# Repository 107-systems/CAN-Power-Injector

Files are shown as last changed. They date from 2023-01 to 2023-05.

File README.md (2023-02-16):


`CAN-Power-Injector`
====================


The purpose of this board is to inject 5V DC power at up to 5A for powering CAN bus devices.

<p align="center">
  
</p>

<p align="center">
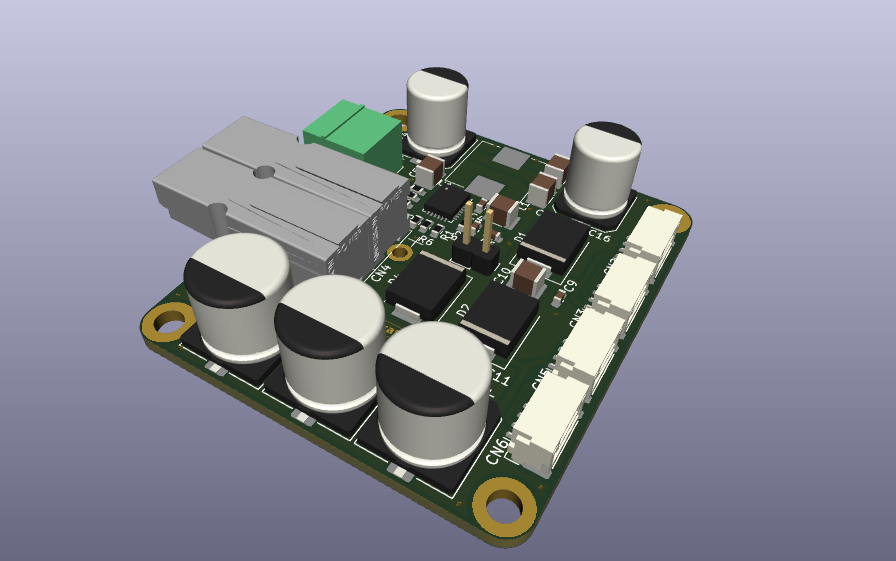
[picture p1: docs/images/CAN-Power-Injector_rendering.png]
  
</p>

#### Blockdiagram
<p align="center">
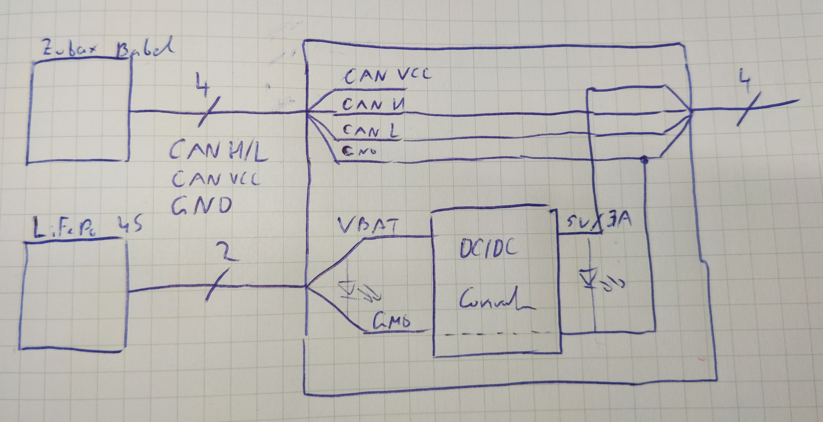
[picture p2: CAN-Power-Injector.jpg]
  
</p>

#### Electrical Parameters
| Name | Value |
|-|-|
| V_IN min | 10.5 V | set by resistor divider(R7/R8) |
| V_IN max | 40.0 V | limited by TVS diode (D4) |
| V_CAN_OUT | 5.0 V to 5.5 V|
| I_CAN_OUT,CONTINUOUS | 5.0 A |

#### Inputs
| Designator | Name | Connector |
|-|-|-|
| CN4 | Battery (4S / 4100 mAh LiFePo) | [Powerpole® PP15 to PP45](https://www.andersonpower.com/content/dam/app/ecommerce/product-pdfs/PP-Pak/ds-pp1545.pdf) |
| CN1 | Battery | 3.5 mm screw terminal (not populated) |

#### Outputs
| Designator | Name | Connector |
|-|-|-|
| CN2 and CN3 | CAN channel 1 | JST GH 1.25mm 4-pin. |
| CN5 and CN6 | CAN channel 2 | JST GH 1.25mm 4-pin. |
| CN7 | 5V | 5V output, internal for testing (not populated) |

## Enclosure

There exists a 3D printable enclosure to encapsulate the PCB.

### Standard
<p align="center">
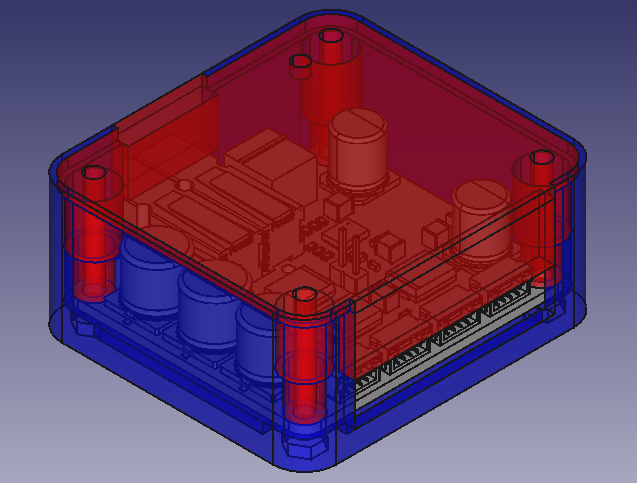
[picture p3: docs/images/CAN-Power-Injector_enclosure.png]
  
</p>

### Low profile
<p align="center">
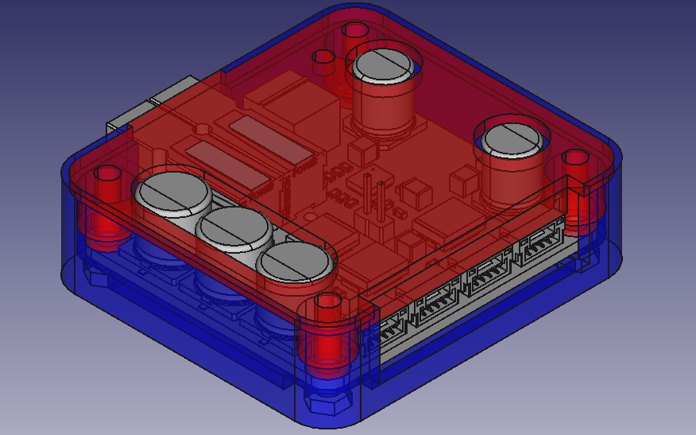
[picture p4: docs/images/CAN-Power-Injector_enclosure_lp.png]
  
</p>

## PCB
### Top
<p align="center">
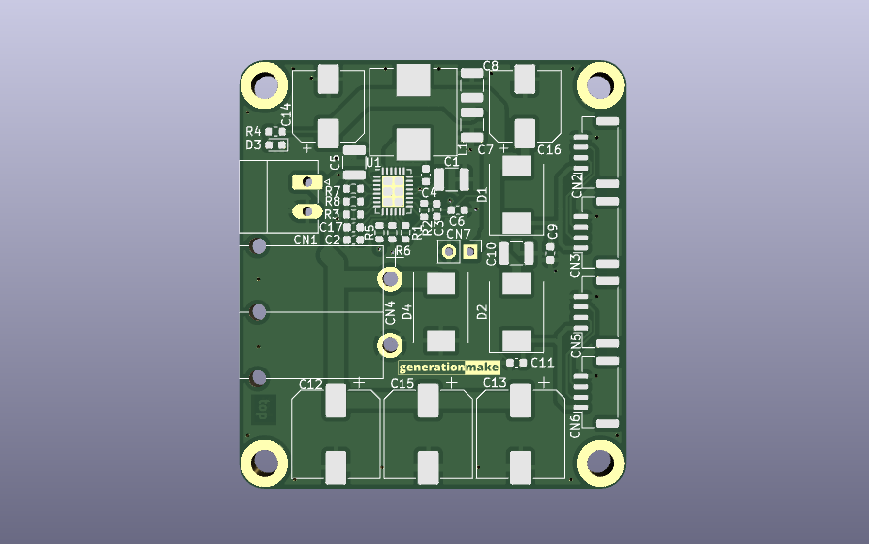
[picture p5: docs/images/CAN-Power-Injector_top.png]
  
</p>

### Bottom
<p align="center">
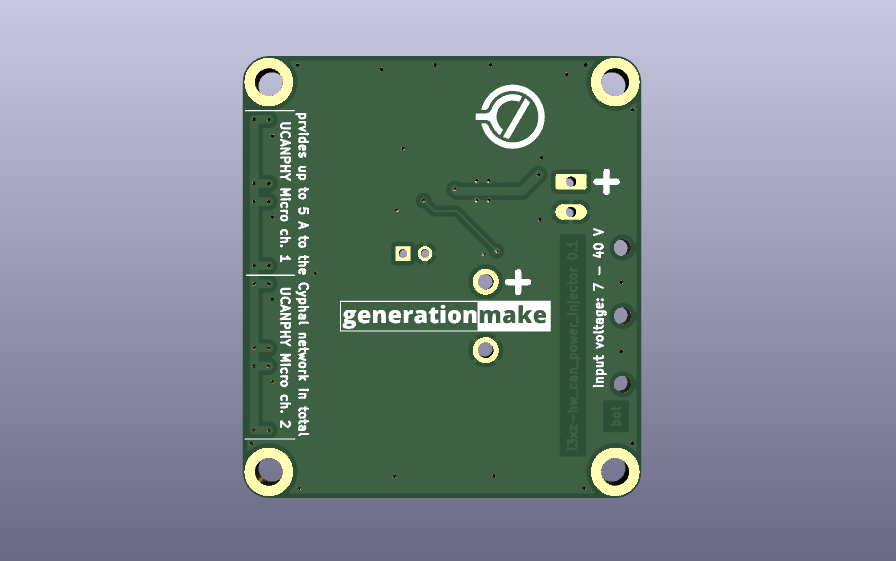
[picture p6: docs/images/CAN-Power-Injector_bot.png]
  
</p>

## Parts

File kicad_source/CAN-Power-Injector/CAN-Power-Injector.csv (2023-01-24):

Source: | /home/bernhard/projects/CAN-Power-Injector/kicad_source/CAN-Power-Injector/CAN-Power-Injector.kicad_sch
Date: | Mi 30 Nov 2022 01:24:45 CET
Tool: | Eeschema 6.0.9-8da3e8f707~116~ubuntu22.04.1
Generator: | /usr/share/kicad/plugins/bom_csv_grouped_by_value.py
Component Count: | 38
Individual Components:
Item | Qty | Reference(s) | Value | LibPart | Footprint | Datasheet
 |  | C1 | 4.7uF 50V | Device:C_Small | Capacitor_SMD:C_1210_3225Metric | ~
 |  | C2 | 1 uF | Device:C_Small | Capacitor_SMD:C_0603_1608Metric | ~
 |  | C3 | 2.2 uF | Device:C_Small | Capacitor_SMD:C_0603_1608Metric | ~
 |  | C4 | 100 nF | Device:C_Small | Capacitor_SMD:C_0603_1608Metric | ~
 |  | C5 | 4.7uF 50V | Device:C_Small | Capacitor_SMD:C_1210_3225Metric | ~
 |  | C6 | 100 nF | Device:C_Small | Capacitor_SMD:C_0603_1608Metric | ~
 |  | C7 | 47uF 10V | Device:C_Small | Capacitor_SMD:C_1210_3225Metric | ~
 |  | C8 | 47uF 10V | Device:C_Small | Capacitor_SMD:C_1210_3225Metric | ~
 |  | C9 | 100 nF | Device:C_Small | Capacitor_SMD:C_0603_1608Metric | ~
 |  | C10 | 47uF 10V | Device:C_Small | Capacitor_SMD:C_1210_3225Metric | ~
 |  | C11 | 100 nF | Device:C_Small | Capacitor_SMD:C_0603_1608Metric | ~
 |  | C12 | 220 uF / 50 V | Device:C_Polarized_Small | Capacitor_SMD:CP_Elec_10x10 | ~
 |  | C13 | 220 uF / 50 V | Device:C_Polarized_Small | Capacitor_SMD:CP_Elec_10x10 | ~
 |  | C14 | 1000 uF / 10 V | Device:C_Polarized_Small | Capacitor_SMD:CP_Elec_8x10 | ~
 |  | C15 | 220 uF / 50 V | Device:C_Polarized_Small | Capacitor_SMD:CP_Elec_10x10 | ~
 |  | C16 | 1000 uF / 10 V | Device:C_Polarized_Small | Capacitor_SMD:CP_Elec_8x10 | ~
 |  | C17 | 10nF | Device:C_Small | Capacitor_SMD:C_0603_1608Metric | ~
 |  | CN1 | DNI | Connector_Generic:Conn_01x02 | Connector_Phoenix_MC:PhoenixContact_MC_1,5_2-G-3.5_1x02_P3.50mm_Horizontal | ~
 |  | CN2 | SM04B-GHS-TB | Connector_Generic_MountingPin:Conn_01x04_MountingPin | Connector_JST:JST_GH_SM04B-GHS-TB_1x04-1MP_P1.25mm_Horizontal | ~
 |  | CN3 | SM04B-GHS-TB | Connector_Generic_MountingPin:Conn_01x04_MountingPin | Connector_JST:JST_GH_SM04B-GHS-TB_1x04-1MP_P1.25mm_Horizontal | ~
 |  | CN4 | Powerpole_2 | Connector_Generic:Conn_01x02 | generationmake:POWERPOLE_hor_2 | ~
 |  | CN5 | SM04B-GHS-TB | Connector_Generic_MountingPin:Conn_01x04_MountingPin | Connector_JST:JST_GH_SM04B-GHS-TB_1x04-1MP_P1.25mm_Horizontal | ~
 |  | CN6 | SM04B-GHS-TB | Connector_Generic_MountingPin:Conn_01x04_MountingPin | Connector_JST:JST_GH_SM04B-GHS-TB_1x04-1MP_P1.25mm_Horizontal | ~
 |  | CN7 | DNI | Connector_Generic:Conn_01x02 | Connector_PinHeader_2.54mm:PinHeader_1x02_P2.54mm_Vertical | ~
 |  | D1 | B520C | Device:D_Schottky_Small | Diode_SMD:D_SMC | ~
 |  | D2 | B520C | Device:D_Schottky_Small | Diode_SMD:D_SMC | ~
 |  | D3 | LED green | Device:LED_Small | LED_SMD:LED_0603_1608Metric | ~
 |  | D4 | SMCJ40A | Device:D_TVS | Diode_SMD:D_SMC | ~
 |  | L1 | 7443251000 (10 uH) | Device:L_Small | Inductor_SMD:L_Wuerth_HCI-1050 | ~
 |  | R1 | 10k | Device:R_Small | Resistor_SMD:R_0603_1608Metric | ~
 |  | R2 | 1R | Device:R_Small | Resistor_SMD:R_0603_1608Metric | ~
 |  | R3 | 30k | Device:R_Small | Resistor_SMD:R_0603_1608Metric | ~
 |  | R4 | 2k2 | Device:R_Small | Resistor_SMD:R_0603_1608Metric | ~
 |  | R5 | 120k | Device:R_Small | Resistor_SMD:R_0603_1608Metric | ~
 |  | R6 | 20k | Device:R_Small | Resistor_SMD:R_0603_1608Metric | ~
 |  | R7 | 120k | Device:R_Small | Resistor_SMD:R_0603_1608Metric | ~
 |  | R8 | 20k | Device:R_Small | Resistor_SMD:R_0603_1608Metric | ~
 |  | U1 | RAA211650 | generationmake:RAA211650 | Package_DFN_QFN:QFN-28-1EP_4x5mm_P0.5mm_EP2.65x3.65mm
Collated Components:
Item | Qty | Reference(s) | Value | LibPart | Footprint | Datasheet
1 | 2 | C1, C5 | 4.7uF 50V | Device:C_Small | Capacitor_SMD:C_1210_3225Metric | ~
2 | 1 | C2 | 1 uF | Device:C_Small | Capacitor_SMD:C_0603_1608Metric | ~
3 | 1 | C3 | 2.2 uF | Device:C_Small | Capacitor_SMD:C_0603_1608Metric | ~
4 | 4 | C4, C6, C9, C11 | 100 nF | Device:C_Small | Capacitor_SMD:C_0603_1608Metric | ~
5 | 3 | C7, C8, C10 | 47uF 10V | Device:C_Small | Capacitor_SMD:C_1210_3225Metric | ~
6 | 3 | C12, C13, C15 | 220 uF / 50 V | Device:C_Polarized_Small | Capacitor_SMD:CP_Elec_10x10 | ~
7 | 2 | C14, C16 | 1000 uF / 10 V | Device:C_Polarized_Small | Capacitor_SMD:CP_Elec_8x10 | ~
8 | 1 | C17 | 10nF | Device:C_Small | Capacitor_SMD:C_0603_1608Metric | ~
9 | 1 | CN1 | DNI | Connector_Generic:Conn_01x02 | Connector_Phoenix_MC:PhoenixContact_MC_1,5_2-G-3.5_1x02_P3.50mm_Horizontal | ~
10 | 4 | CN2, CN3, CN5, CN6 | SM04B-GHS-TB | Connector_Generic_MountingPin:Conn_01x04_MountingPin | Connector_JST:JST_GH_SM04B-GHS-TB_1x04-1MP_P1.25mm_Horizontal | ~
11 | 1 | CN4 | Powerpole_2 | Connector_Generic:Conn_01x02 | generationmake:POWERPOLE_hor_2 | ~
12 | 1 | CN7 | DNI | Connector_Generic:Conn_01x02 | Connector_PinHeader_2.54mm:PinHeader_1x02_P2.54mm_Vertical | ~
13 | 2 | D1, D2 | B520C | Device:D_Schottky_Small | Diode_SMD:D_SMC | ~
14 | 1 | D3 | LED green | Device:LED_Small | LED_SMD:LED_0603_1608Metric | ~
15 | 1 | D4 | SMCJ40A | Device:D_TVS | Diode_SMD:D_SMC | ~
16 | 1 | L1 | 7443251000 (10 uH) | Device:L_Small | Inductor_SMD:L_Wuerth_HCI-1050 | ~
17 | 1 | R1 | 10k | Device:R_Small | Resistor_SMD:R_0603_1608Metric | ~
18 | 1 | R2 | 1R | Device:R_Small | Resistor_SMD:R_0603_1608Metric | ~
19 | 1 | R3 | 30k | Device:R_Small | Resistor_SMD:R_0603_1608Metric | ~
20 | 1 | R4 | 2k2 | Device:R_Small | Resistor_SMD:R_0603_1608Metric | ~
21 | 2 | R5, R7 | 120k | Device:R_Small | Resistor_SMD:R_0603_1608Metric | ~
22 | 2 | R6, R8 | 20k | Device:R_Small | Resistor_SMD:R_0603_1608Metric | ~
23 | 1 | U1 | RAA211650 | generationmake:RAA211650 | Package_DFN_QFN:QFN-28-1EP_4x5mm_P0.5mm_EP2.65x3.65mm

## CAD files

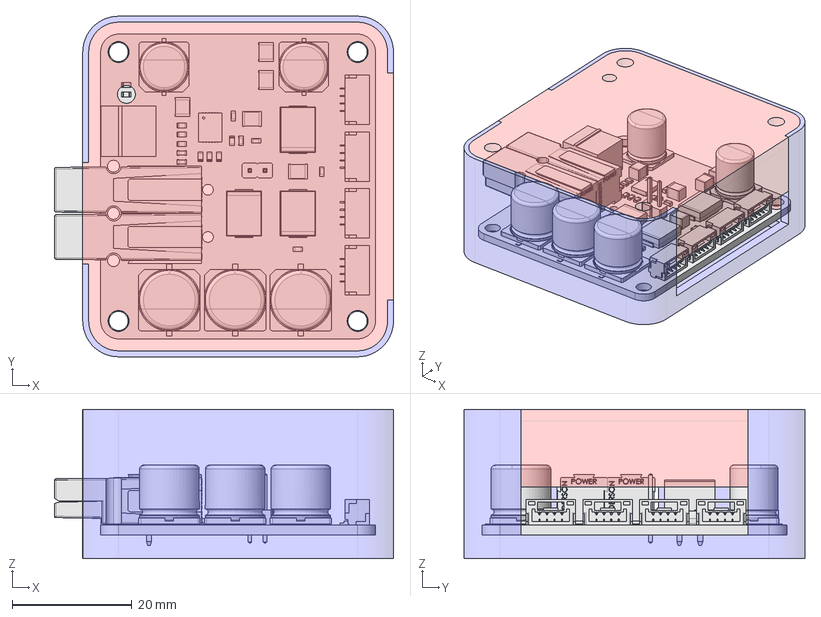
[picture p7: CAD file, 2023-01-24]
freecad_source/enclosure.FCStd
56.7 x 57.0 x 25.0 mm
bottom
l3xz-hw_can_power_injector
top

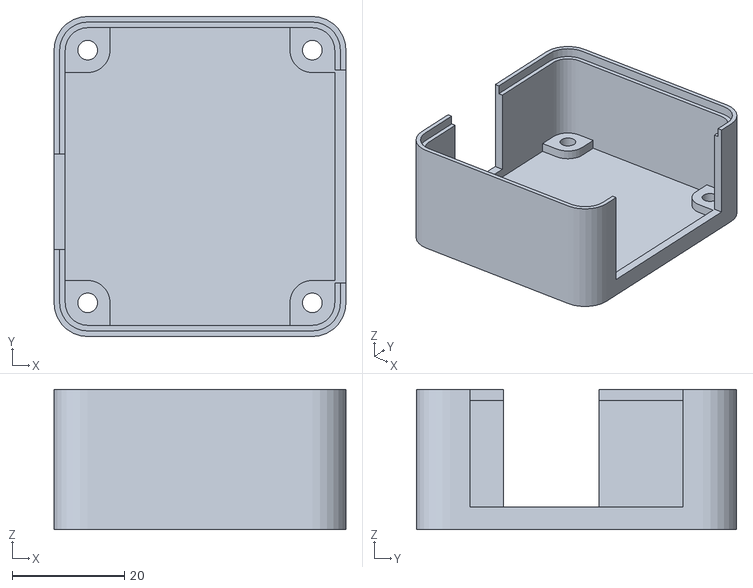
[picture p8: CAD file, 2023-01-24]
production_data/enclosure-bottom.stl
52.0 x 57.0 x 25.0

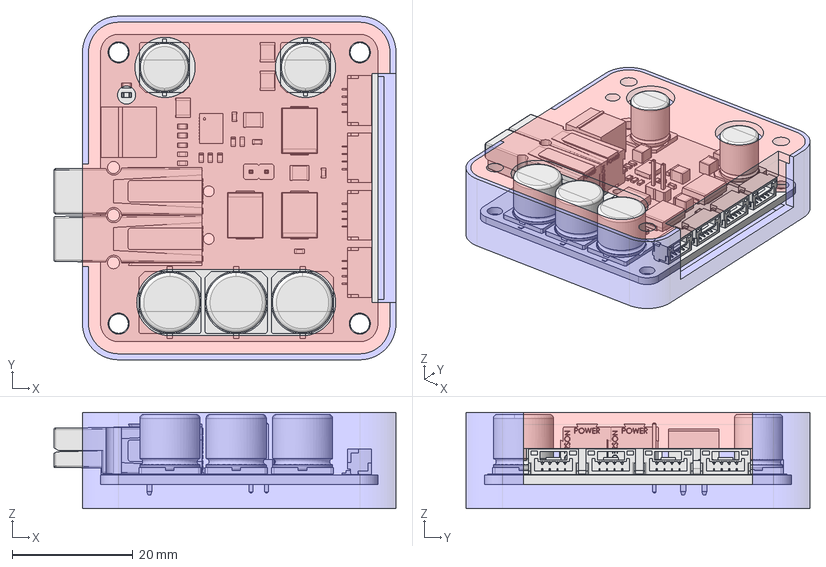
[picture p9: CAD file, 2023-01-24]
freecad_source/enclosure_lp.FCStd
56.7 x 57.0 x 16.0 mm
bottom
l3xz-hw_can_power_injector
top

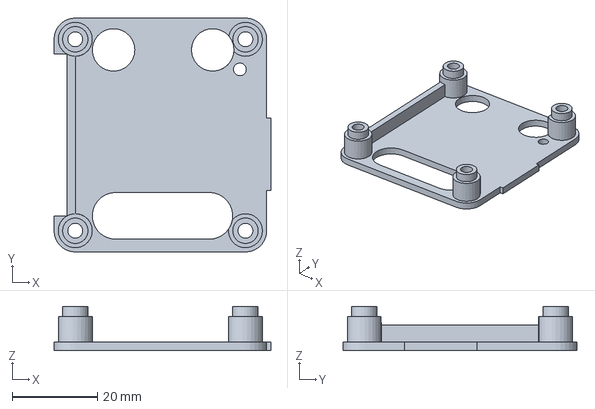
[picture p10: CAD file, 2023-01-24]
production_data/enclosure_lp-top.3mf
51.0 x 55.0 x 10.4 mm

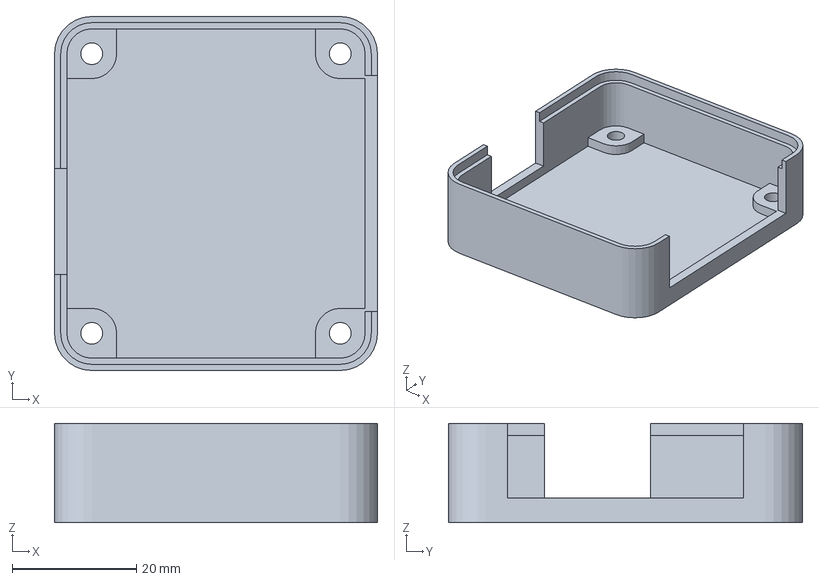
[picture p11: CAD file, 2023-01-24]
production_data/enclosure_lp-bottom.3mf
52.0 x 57.0 x 16.0 mm

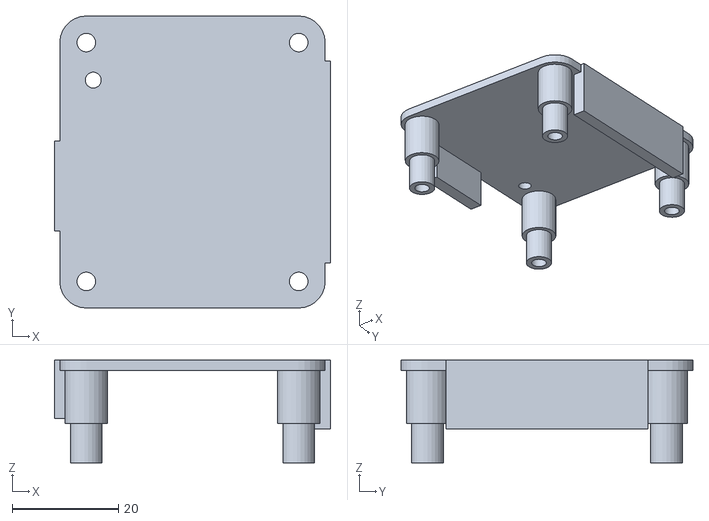
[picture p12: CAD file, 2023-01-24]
production_data/enclosure-top.stl
52.0 x 55.0 x 19.4

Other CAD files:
production_data/enclosure_lp-bottom.stl
production_data/enclosure_lp-top.stl

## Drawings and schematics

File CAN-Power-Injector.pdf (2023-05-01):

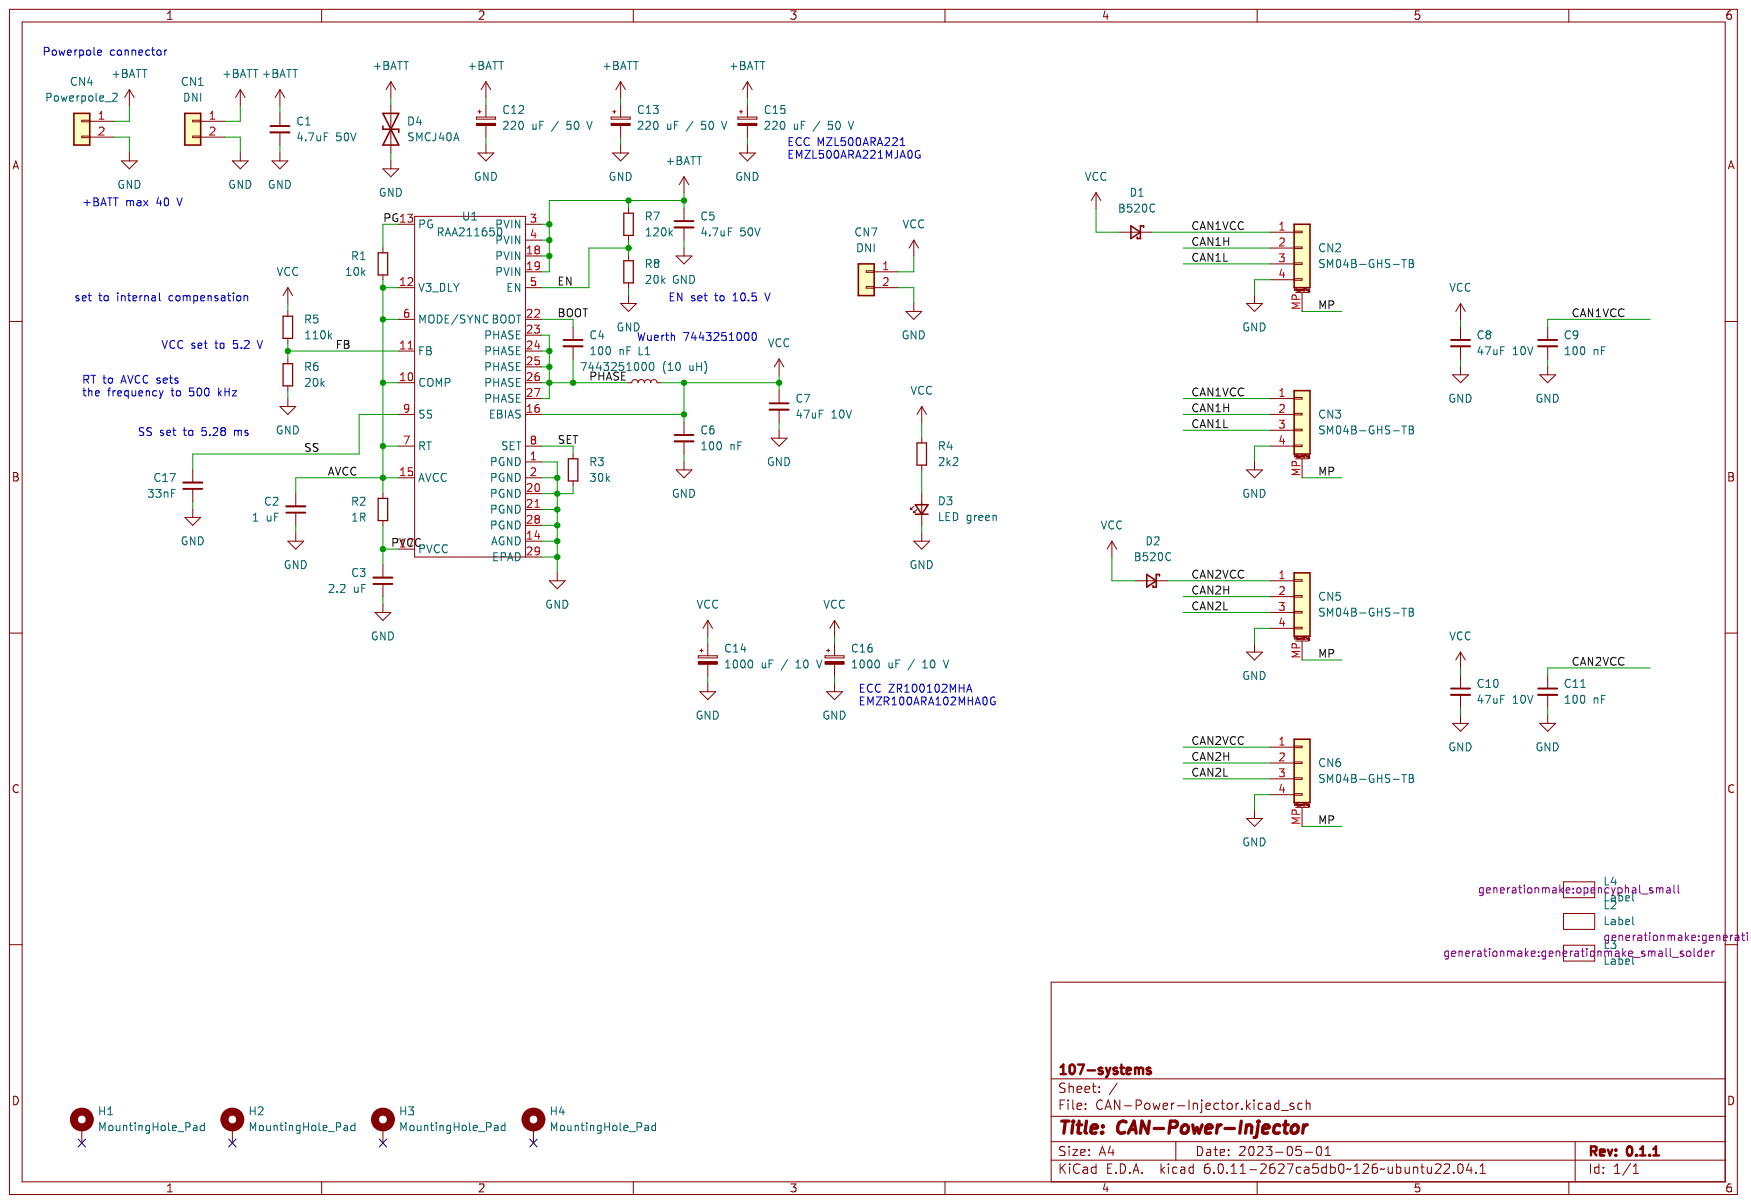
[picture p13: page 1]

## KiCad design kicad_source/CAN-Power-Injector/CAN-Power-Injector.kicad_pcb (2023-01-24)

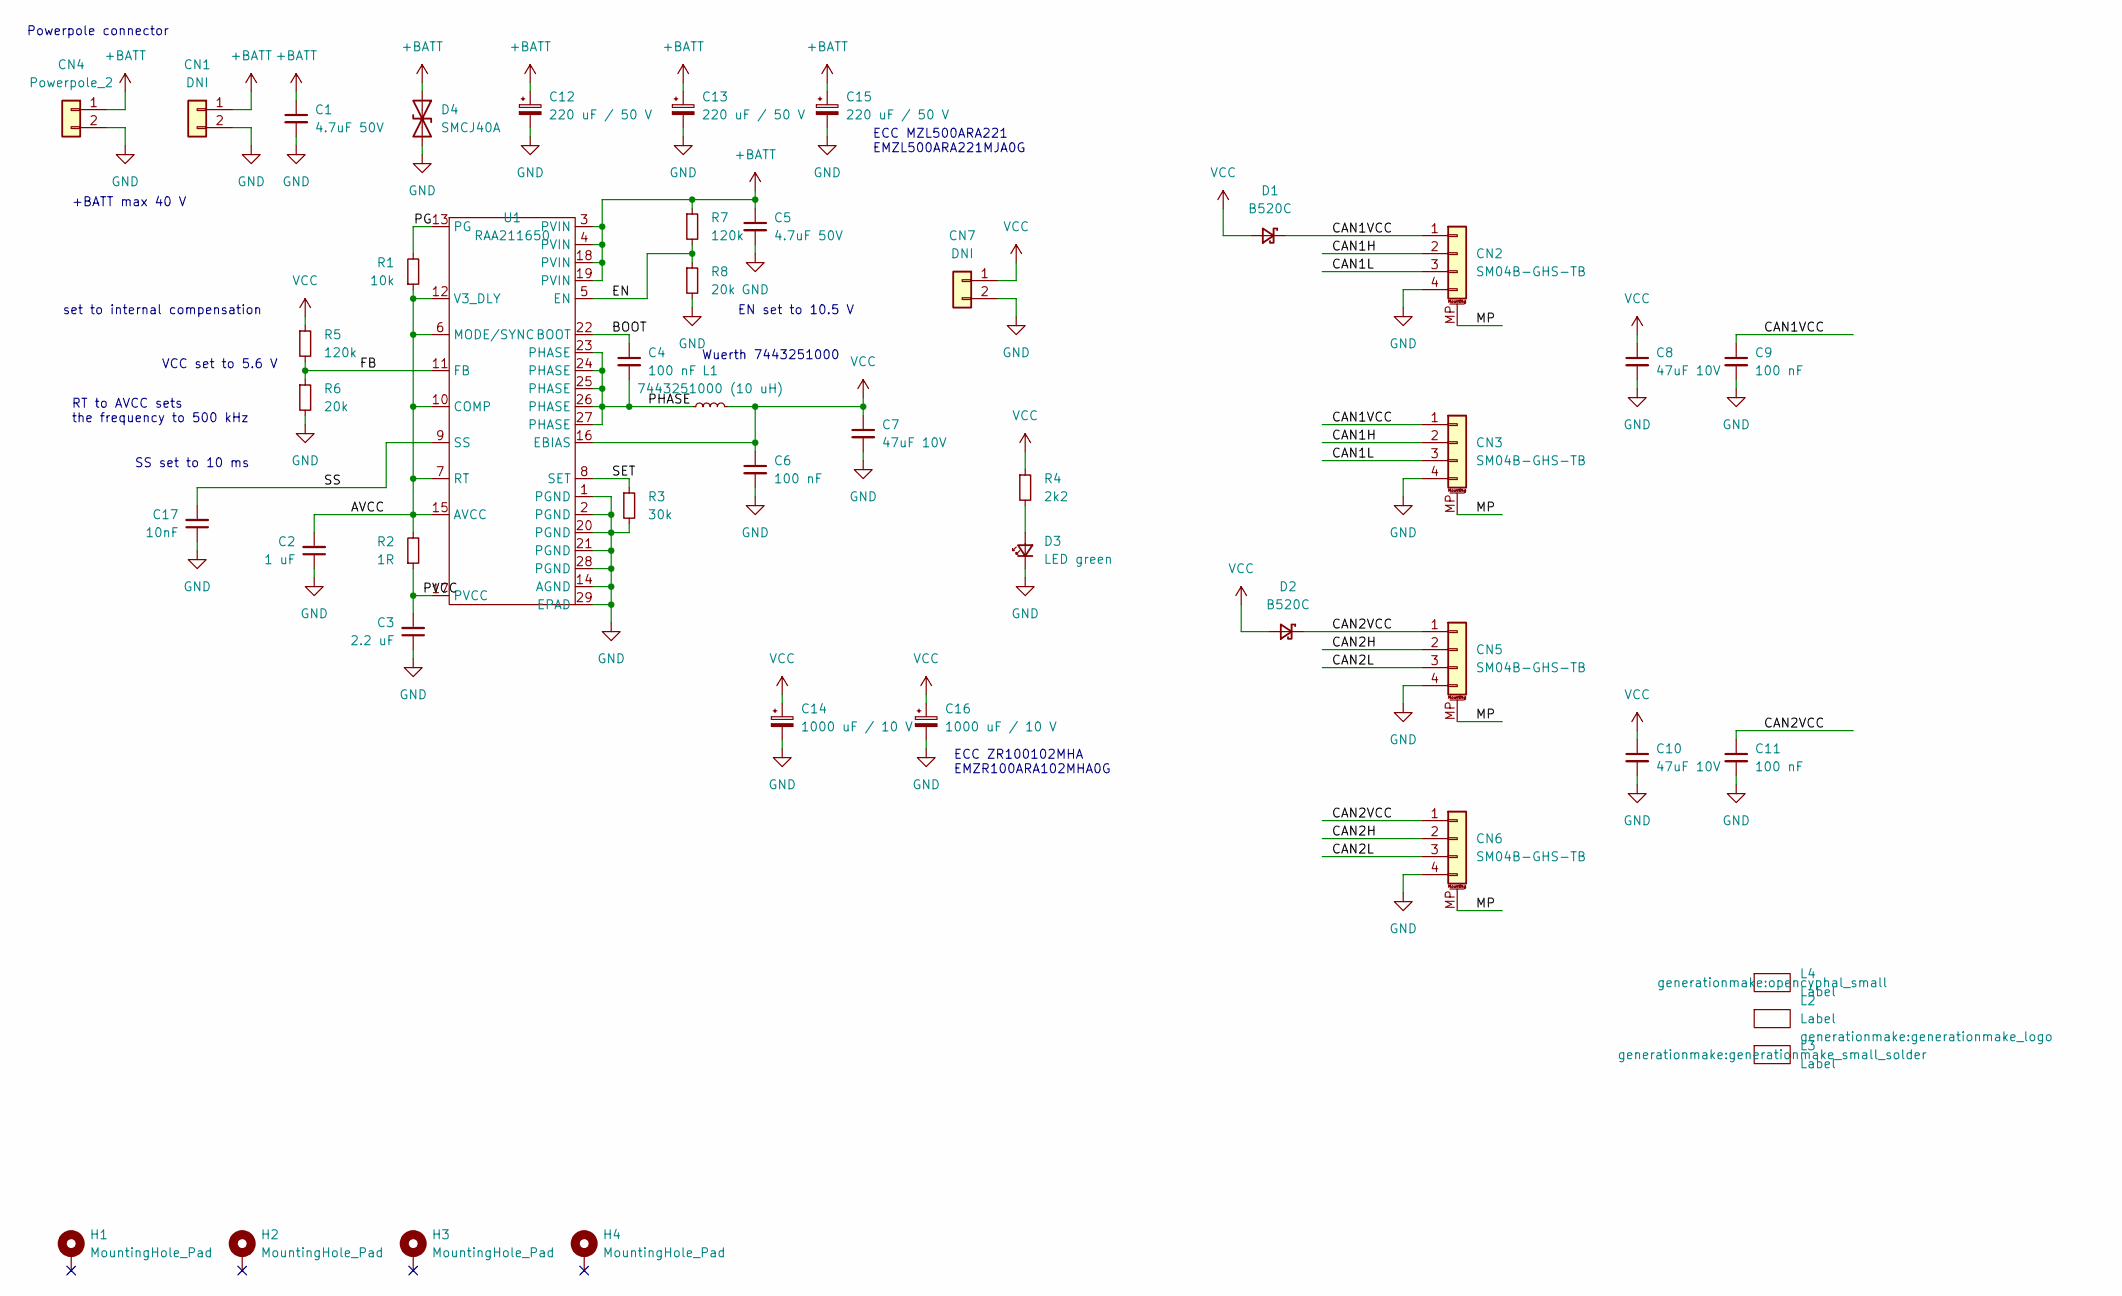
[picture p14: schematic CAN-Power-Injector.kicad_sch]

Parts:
C1, C5: 4.7uF 50V; C_1210_3225Metric
C2: 1 uF; C_0603_1608Metric
C3: 2.2 uF; C_0603_1608Metric
C4, C6, C9, C11: 100 nF; C_0603_1608Metric
C7, C8, C10: 47uF 10V; C_1210_3225Metric
C12, C13, C15: 220 uF / 50 V; CP_Elec_10x10
C14, C16: 1000 uF / 10 V; CP_Elec_8x10
C17: 10nF; C_0603_1608Metric
CN1: DNI; PhoenixContact_MC_1,5_2-G-3.5_1x02_P3.50mm_Horizontal
CN2, CN3, CN5, CN6: SM04B-GHS-TB; JST_GH_SM04B-GHS-TB_1x04-1MP_P1.25mm_Horizontal
CN4: Powerpole_2; POWERPOLE_hor_2
CN7: DNI; PinHeader_1x02_P2.54mm_Vertical
D1, D2: B520C; D_SMC
D3: LED green; LED_0603_1608Metric
D4: SMCJ40A; D_SMC
H1, H2, H3, H4: MountingHole_Pad; MountingHole_3.2mm_M3_DIN965_Pad
L1: 7443251000 (10 uH); L_Wuerth_HCI-1050
L2: Label; generationmake_logo
L3: Label; generationmake_small_solder
L4: Label; opencyphal_small
R1: 10k; R_0603_1608Metric
R2: 1R; R_0603_1608Metric
R3: 30k; R_0603_1608Metric
R4: 2k2; R_0603_1608Metric
R5, R7: 120k; R_0603_1608Metric
R6, R8: 20k; R_0603_1608Metric
U1: RAA211650; QFN-28-1EP_4x5mm_P0.5mm_EP2.65x3.65mm

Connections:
+BATT: C1.1, C5.1, C12.1, C13.1, C15.1, CN1.1, CN4.1, D4.1 (A1), R7.1, U1.3 (PVIN), U1.4 (PVIN), U1.18 (PVIN), U1.19 (PVIN)
/AVCC: C2.2, R1.1, R2.2, U1.6 (MODE/SYNC), U1.7 (RT), U1.10 (COMP), U1.12 (V3_DLY), U1.15 (AVCC)
/BOOT: C4.1, U1.22 (BOOT)
/CAN1H: CN2.2, CN3.2
/CAN1L: CN2.3, CN3.3
/CAN1VCC: C9.1, CN2.1, CN3.1, D1.1 (K)
/CAN2H: CN5.2, CN6.2
/CAN2L: CN5.3, CN6.3
/CAN2VCC: C11.1, CN5.1, CN6.1, D2.1 (K)
/EN: R7.2, R8.1, U1.5 (EN)
/FB: R5.2, R6.1, U1.11 (FB)
/MP: CN2.MP (MountPin), CN3.MP (MountPin), CN5.MP (MountPin), CN6.MP (MountPin)
/PG: R1.2, U1.13 (PG)
/PHASE: C4.2, L1.1, U1.23 (PHASE), U1.24 (PHASE), U1.25 (PHASE), U1.26 (PHASE), U1.27 (PHASE)
/PVCC: C3.2, R2.1, U1.17 (PVCC)
/SET: R3.1, U1.8 (SET)
/SS: C17.2, U1.9 (SS)
GND: C1.2, C2.1, C3.1, C5.2, C6.2, C7.2, C8.2, C9.2, C10.2, C11.2, C12.2, C13.2, C14.2, C15.2, C16.2, C17.1, CN1.2, CN2.4, CN3.4, CN4.2, CN5.4, CN6.4, CN7.2, D3.1 (K), D4.2 (A2), R3.2, R6.2, R8.2, U1.1 (PGND), U1.2 (PGND), U1.14 (AGND), U1.20 (PGND), U1.21 (PGND), U1.28 (PGND), U1.29 (EPAD)
unnamed: D3.2 (A), R4.2
VCC: C6.1, C7.1, C8.1, C10.1, C14.1, C16.1, CN7.1, D1.2 (A), D2.2 (A), L1.2, R4.1, R5.1, U1.16 (EBIAS)

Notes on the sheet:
Wuerth 7443251000
EN set to 10.5 V
+BATT max 40 V
ECC ZR100102MHA EMZR100ARA102MHA0G
set to internal compensation
ECC MZL500ARA221 EMZL500ARA221MJA0G
RT to AVCC sets the frequency to 500 kHz
VCC set to 5.6 V
Powerpole connector
SS set to 10 ms

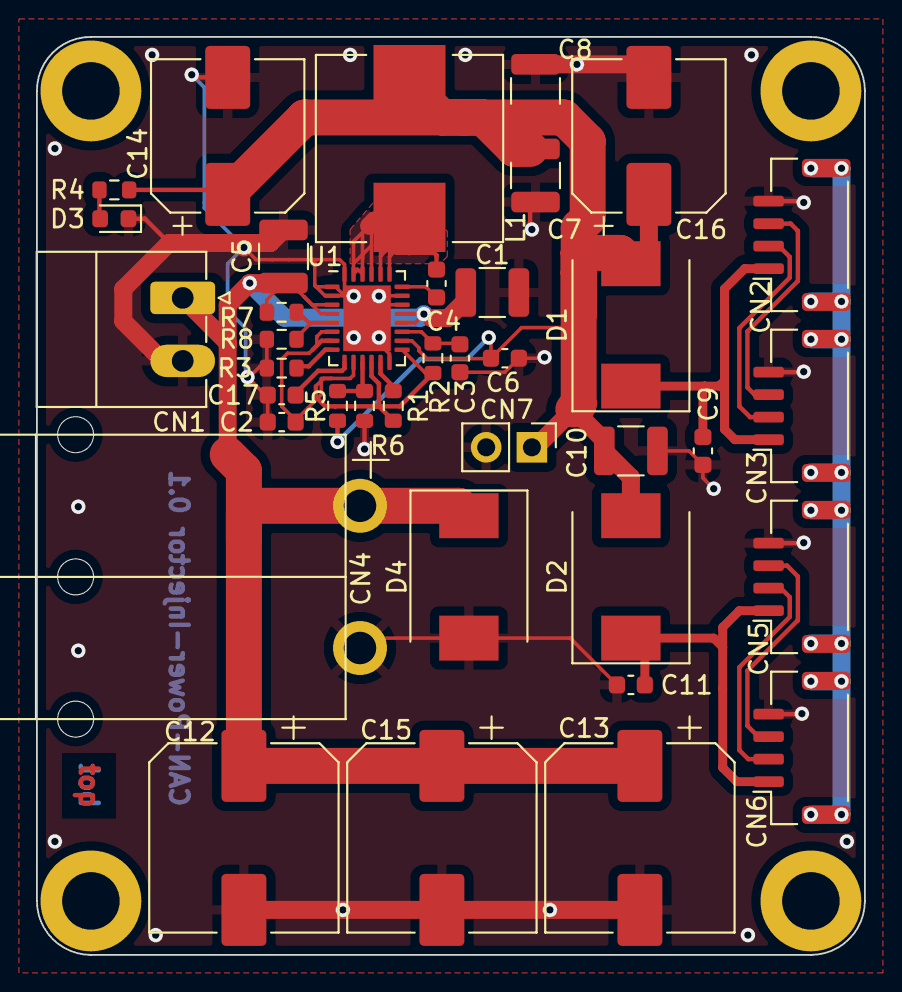
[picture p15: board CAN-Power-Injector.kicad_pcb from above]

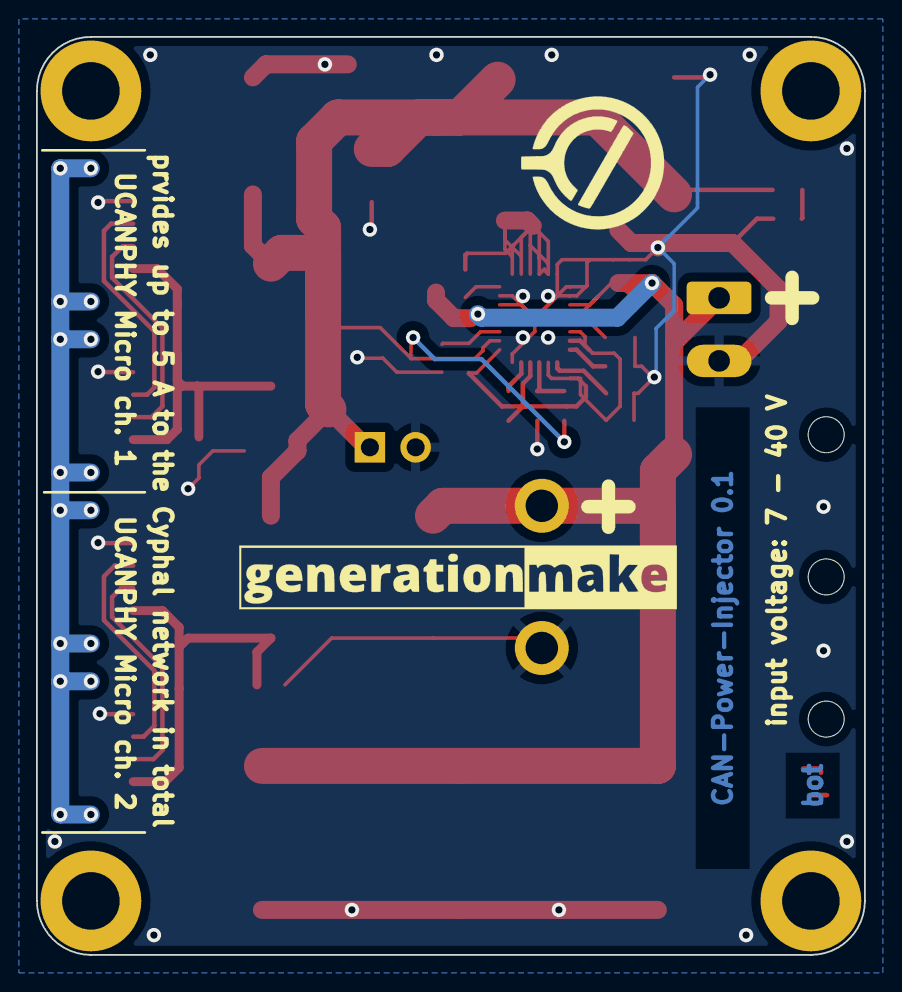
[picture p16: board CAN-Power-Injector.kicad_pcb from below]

Board: 2 copper layers, 46.0 x 51.0 mm, 45 parts (2 on the bottom side), 20 nets.

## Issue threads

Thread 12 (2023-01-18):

[Feature Request] Increase hole diameter of top enclosure casing from 3.2 to 3.5 mm

aentinger, 2023-01-18:
<a href="https://107-systems.org/">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</a>

### ⚡ Feature Request

Currently the diameter is at 3.2 mm, should be increased to 3.5 mm (no cutting screws used).

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

Closed 2023-01-24.

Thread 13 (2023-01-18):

[Feature Request] Reduce overall height of bottom enclosure from 25 mm to 15 mm

aentinger, 2023-01-18:
<a href="https://107-systems.org/">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</a>

### ⚡ Feature Request

Please re-design the top accordingly, this needs the planning of cut-outs where the capacitory are placed. With a total height of 15 mm the power-pole connectors should be firmly squeezed in place by the top enclosure.

Closed 2023-01-24.

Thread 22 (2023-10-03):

[Feature Request] Prepare for manufacturing

aentinger, 2023-10-03:
<a href="https://107-systems.org/">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</a>

### ⚡ Feature Request

Hi @generationmake :coffee: :wave:

Can you please prepare this repository for manufacturing by our usual manufacturing partner? I'd like to have a couple of those made ... possibly even a topic for a online store.

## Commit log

2022-10-23 added kicad project
    [l3xz-hw_can_power_injector.kicad_pcb, l3xz-hw_can_power_injector.kicad_sch]
2022-10-24 added switching regulator to schematic
    [l3xz-hw_can_power_injector.kicad_sch]
2022-10-24 updated and annotated schematic
    [l3xz-hw_can_power_injector.kicad_sch]
2022-10-24 started layout
    [l3xz-hw_can_power_injector.kicad_pcb, l3xz-hw_can_power_injector.kicad_sch]
2022-10-24 added images of pcb
2022-10-25 added Powerpole connector
    [l3xz-hw_can_power_injector.kicad_pcb, l3xz-hw_can_power_injector.kicad_sch]
2022-10-30 addedhoricontal powerpole
    [l3xz-hw_can_power_injector.kicad_pcb, l3xz-hw_can_power_injector.kicad_sch]
2022-10-31 added second uavcan channel and diodes
    [l3xz-hw_can_power_injector.kicad_pcb, l3xz-hw_can_power_injector.kicad_sch]
2022-10-31 added LED
    [l3xz-hw_can_power_injector.kicad_pcb, l3xz-hw_can_power_injector.kicad_sch]
2022-10-31 added TVS diode and capacitors, updated layout
    [l3xz-hw_can_power_injector.kicad_pcb, l3xz-hw_can_power_injector.kicad_sch]
2022-11-04 changed connector for input, added connector for VCC
    [l3xz-hw_can_power_injector.kicad_pcb, l3xz-hw_can_power_injector.kicad_sch]
2022-11-05 updated and set analog values of switching regulator
    [l3xz-hw_can_power_injector.kicad_pcb, l3xz-hw_can_power_injector.kicad_sch]
2022-11-06 added enable on VIN
    [l3xz-hw_can_power_injector.kicad_pcb, l3xz-hw_can_power_injector.kicad_sch]
2022-11-06 updated some component values
    [l3xz-hw_can_power_injector.kicad_pcb, l3xz-hw_can_power_injector.kicad_sch]
2022-11-06 made drc, corrected some errors, added label
    [l3xz-hw_can_power_injector.kicad_pcb, l3xz-hw_can_power_injector.kicad_sch]
2022-11-07 updated schematic pdf and images
    [l3xz-hw_can_power_injector.kicad_sch]
2022-11-30 added some texts to pcb, generated BOM, updated schemtatic pdf
    [l3xz-hw_can_power_injector.csv, l3xz-hw_can_power_injector.kicad_pcb, l3xz-hw_can_power_injector.kicad_sch]
2022-12-12 added some labels
    [l3xz-hw_can_power_injector.kicad_pcb, l3xz-hw_can_power_injector.kicad_sch]
2023-01-06 added step file of pcb
    [l3xz-hw_can_power_injector.kicad_pcb]
2023-01-06 added freecad project with enclosure
    [enclosure.FCStd]
2023-01-06 added production data with stl files
    [enclosure-bottom.stl, enclosure-top.stl]
2023-01-06 added image of enclosure
2023-01-06 made design transparent
    [enclosure.FCStd]
2023-01-08 increased enclosure height by 3 mm, added hex holes on bottom
    [enclosure.FCStd]
2023-01-08 improved spacer
    [enclosure.FCStd]
2023-01-08 updated image and production data
    [enclosure-bottom.stl, enclosure-top.stl]
2023-01-20 increased hole size
    [enclosure-bottom.stl, enclosure-top.stl, enclosure.FCStd]
2023-01-20 designed low profile enclosure
    [enclosure_lp-bottom.stl, enclosure_lp-top.stl, enclosure_lp.FCStd]
2023-01-20 added image of low profile enclosure
2023-01-20 Adding Prusa Slicer Project files and GCode to production data.
    [enclosure_lp-bottom.3mf, enclosure_lp-top.3mf]
2023-01-21 increased hole size for capacitors by 1 mm, added blocking wall near the can connectors
    [enclosure_lp-top.stl, enclosure_lp.FCStd]
2023-01-22 add prusa slicer project
    [enclosure_lp-top_wuehr1999_pla.3mf]
2023-01-24 Update production data.
    [enclosure_lp-top.3mf, enclosure_lp-top_wuehr1999_pla.3mf]
2023-01-24 Rename all files to CAN-Power-Injector.
    [CAN-Power-Injector.csv, CAN-Power-Injector.kicad_pcb, CAN-Power-Injector.kicad_sch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]
2023-02-16 Add CI workflow to check for commonly misspelled words
    On every push, pull request, and periodically, use codespell to check for commonly
    misspelled words.
    In the event of a false positive, the problematic word should be added, in all lowercase, to the
    field of . Regardless of the case of the word in the false positive, it must be in all lowercase in the
    ignore list. The ignore list is comma-separated with no spaces.
2023-05-01 changed R5 to 110 k. this changes VCC to 5.2V
    [CAN-Power-Injector.kicad_sch]
2023-05-01 increased C17 to 33 nF to achieve a soft start of 5.28 ms because of high output capacitance
    [CAN-Power-Injector.kicad_sch]
2023-05-01 updated schematic pdf
